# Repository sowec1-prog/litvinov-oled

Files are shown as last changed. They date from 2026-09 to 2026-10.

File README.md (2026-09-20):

# Litvínov OLED scoreboard

Autonomní hokejový panel pro **ESP32-C3 SuperMini** a OLED SSD1306 128×64. Firmware čte kompaktní stav z `https://litvinov-server.onrender.com/api/live`; PC ani LVGL nejsou potřeba.

## Funkce

- živé skóre, týmové kódy a poslední střelec bez diakritiky;
- `TRES-LIT`, `TRES-PCE` nebo `TRES-LIT/PCE` podle strukturované události píšťalky;
- přestávka s lokálním odpočtem bez cloudových dotazů;
- lokální odpočet příštího zápasu;
- gól Litvínova: znělka a 30sekundová blikající animace `GOOL` zprava doleva;
- první přijatý gól po restartu animaci ani zvuk nespustí;
- konečný výsledek se na cloudovém API drží pět minut jako `ZAPAS SKONCIL`.

## Použitý hardware

- **ESP32-C3 SuperMini** — ESP32-C3, 4 MB flash, Wi-Fi 2,4 GHz; projekt používá PlatformIO profil `esp32-c3-devkitm-1`.
- **OLED SSD1306 128 × 64 px**, I²C, adresa `0x3C`.
- **Pasivní piezo bzučák** ověřený pro PWM tóny.
- USB datový kabel pro napájení a nahrání firmwaru.
- Propojovací vodiče: 4× pro OLED, 2× pro bzučák.

## Zapojení

Všechny moduly musí mít společnou zem (**GND**). OLED i GPIO ESP32-C3 jsou 3,3 V logika; OLED proto napájejte z pinu **3V3**, ne z 5 V.

| ESP32-C3 SuperMini | Připojit na | Poznámka |
|---|---|---|
| GPIO8 | OLED SDA | I²C data |
| GPIO9 | OLED SCL | I²C hodiny |
| 3V3 | OLED VCC | napájení OLED |
| GND | OLED GND | společná zem |
| GPIO4 | piezo `+` / signál | PWM znělka |
| GND | piezo `-` | společná zem |

OLED používá I²C adresu `0x3C`.

## Nastavení Wi-Fi

1. Zkopírujte `include/secrets.h.example` jako `include/secrets.h`.
2. Doplňte primární SSID/heslo a případně `WIFI_SSID_2` / `WIFI_PASSWORD_2` a `WIFI_SSID_3` / `WIFI_PASSWORD_3` pro další místa.
3. ESP32-C3 vybere první dostupnou uloženou 2,4GHz síť; po návratu domů se automaticky připojí k domácí Wi-Fi.
4. Pokud se žádná uložená síť nepřipojí do 45 sekund, OLED vytvoří zabezpečený hotspot **`Litvinov-OLED-Setup`** s heslem **`litvinov`**. Připojte se k němu telefonem, otevřete `http://192.168.4.1`, vyberte nalezenou síť a zadejte její heslo. Seznam obsahuje pouze 2,4GHz sítě kompatibilní s ESP32-C3.
5. Po úspěšném připojení hotspot zmizí; nově vybraná síť se uloží do paměti ESP spolu s dříve zadanými sítěmi.
6. Soubor `include/secrets.h` nikdy necommitujte; `.gitignore` jej vylučuje.

## Sestavení a nahrání

Vyžaduje PlatformIO a desku `esp32-c3-devkitm-1`.

```bash
uv run --with platformio pio run
uv run --with esptool esptool --chip esp32c3 --port COM3 --baud 460800 --no-stub write-flash \
  0x0 .pio/build/esp32-c3-devkitm-1/bootloader.bin \
  0x8000 .pio/build/esp32-c3-devkitm-1/partitions.bin \
  0x10000 .pio/build/esp32-c3-devkitm-1/firmware.bin
uv run --with esptool esptool --chip esp32c3 --port COM3 --baud 460800 --no-stub verify-flash \
  0x10000 .pio/build/esp32-c3-devkitm-1/firmware.bin
```

Předchozí funkční flash i zdrojová záloha zůstávají lokálně. Fyzické chování OLED a animace se ověřuje při skutečné nové události v přenosu.

## Použité knihovny

- Adafruit GFX 1.11.11
- Adafruit SSD1306 2.5.13
- ArduinoJson 7.1.0
- espressif32 6.7.0

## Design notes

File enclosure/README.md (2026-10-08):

# Krabička pro Litvínov OLED — revize A

Parametrický OpenSCAD návrh pro přenosný OLED panel. Zdroj: `litvinov_oled_case.scad`.

## Použité rozměry

| Díl | Rozměr použitý v modelu | Zdroj |
|---|---:|---|
| LiPol 855085 s ochranou | 85 × 50 × 8,5 mm | produktový list |
| OLED 1,3" / 7 pin | 35,5 × 33,7 mm; 4 × Ø3,0 mm | dodaný mechanický výkres |
| OLED uchycení | 4 × Ø2,2 mm zatavovací kolík; rozteč 31,5 × 29,7 mm | navrženo podle výkresu |
| ESP32-C3 s piny/bzučákem | 40 × 30 mm obrys | změřeno uživatelem |
| TP4056 USB-C | 20 × 15 × 5 mm | dodaný obrázek modulu |
| SS12F15 | otvor 14 × 3,4 mm | nutno doladit podle konkrétní výšky páčky |

## Konstrukce

- Vnější rozměr: **60 × 96 × 28 mm**.
- Zadní vana drží baterii na dně v prostoru 52 × 87 × 9,5 mm. Baterii nepřiskřípnout: vložit 0,5–1 mm pěnovou pásku, nepoužívat šrouby ani ostré výstupky v jejím okolí.
- Přední díl je bezel pro OLED. Čtyři pružné západky jej drží v zadní vaně; samotný OLED drží čtyři Ø2,2mm plastové kolíky vedené jeho otvory Ø3mm a po zkoušce se zataví páječkou.
- Konstrukce je **bez šroubů**: víčko drží pružné západky a OLED čtyři zatavovací piny. Pro sestavení tedy nejsou potřeba žádné šrouby ani matice.
- Baterie leží při zadní stěně. ESP32-C3 je nalepený svisle na vnitřní stranu předního bezelu pod OLEDem, takže piny zespodu nikdy neleží na LiPol a nahoře zůstává prostor pro bzučák.
- Na **zadní velké ploše** jsou vedle sebe USB-C otvor TP4056 a štěrbina posuvného vypínače. TP4056 se lepí uvnitř přímo za svůj otvor.
- Západky jsou vedené z předního bezelu do nízko umístěných oken zadní vany; bezel se zacvakává z přední strany, ne obráceně.

## Před tiskem: nutné suché ověření

1. Změř šířku a výšku **páčky** konkrétního SS12F15; v modelu jsou parametry `switch_slot_w` a `switch_slot_h`.
2. Zkus nejdřív pouze přední díl a ověř OLED. Rozměr prosvětlené plochy `oled_view_w/h` je startovní hodnota; není to rozměr desky.
3. Pro samostatné STL otevři a exportuj tyto dva soubory: `litvinov_oled_case_FRONT.scad` (přední bezel) a `litvinov_oled_case_REAR.scad` (zadní vana). Hlavní `litvinov_oled_case.scad` nyní ve výchozím nastavení ukazuje oba díly odděleně 8 mm od sebe na jedné tiskové ploše; režim `assembly` je jen kontrolní náhled, nikdy jej neexportuj pro tisk.
4. Tisk pro **FLSun T1 / ABS**: vrstva 0,20 mm, 4 perimetry, 5 horních i spodních vrstev, 18 % gyroid, 8mm brim. Připravený profil `0.20mm ABS enclosure @FLSun T1 - Litvinov` je už uložený přímo v OrcaSliceru. Použij existující filamentový profil **FLSun T1 ABS** (jeho systémové výchozí hodnoty jsou 280 °C tryska / 90 °C podložka). Před tiskem ABS tiskárnu uzavři, vysuš filament a zapni filtraci/odtah podle běžného postupu pro ABS.
5. Přední bezel tiskni čelem dolů, zadní vanu dnem dolů. **Podpěry jsou v profilu vypnuté.** Konstrukce nemá žádné vnitřní police ani kolejnice vyžadující podporu; krátké můstky západek jsou maximálně 1,8 mm.

## Elektrická bezpečnost

- TP4056 připojit k LiPol pouze po ověření polarity `B+` / `B−`.
- USB-C otvor je pro **nabíjení TP4056**, ne pro přímé připojení článku k ESP.
- Baterii nepropichovat, nemačkat, nešroubovat přes ni a nepoužívat ji, pokud je nafouklá nebo se nabíjení zahřívá.
- Než krabičku zavřeš napevno, vyzkoušej nabíjení, vypínač, OLED a bzučák.

## Stav ověření

Model i oba STL soubory byly nyní skutečně vyexportovány přes OpenSCAD a zkontrolovány: každý STL obsahuje právě jeden souvislý tiskový díl. Rozměrová zkouška prvního výtisku zůstává nutná pro konkrétní páčku vypínače, výšku bzučáku a skutečný OLED před zatavením kolíků.

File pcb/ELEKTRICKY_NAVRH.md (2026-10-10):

# Litvínov OLED — elektrický návrh modulové PCB rev. A

Tato deska je nosná PCB pro stávající ESP32-C3 SuperMini. OLED, bzučák, článek 18650 a USB-C nabíjení jsou připojené přes desku; firmware a Wi-Fi anténa SuperMini zůstávají beze změny.

> Stav: návrh zapojení před rozmístěním součástek. Neobjednávat PCB ani nepřipojovat baterii, dokud nebude ověřen skutečný pinový rastr SuperMini, nabíjecí modul a rozměr držáku 18650.

## OLED — univerzální čtyřpinový konektor

OLEDy, které připadají v úvahu, mají oba pořadí `SCL, SDA` na pinech 3/4, ale liší se prohozeným napájením na pinech 1/2:

| Pin OLED konektoru | Typ A | Typ B | Funkce na PCB |
|---:|---|---|---|
| 1 | GND | VIN | volitelné přes pájecí propojku |
| 2 | VIN | GND | volitelné přes pájecí propojku |
| 3 | SCL | SCL | GPIO9 |
| 4 | SDA | SDA | GPIO8 |

- `VIN` OLEDu je vždy **3,3 V**, nikdy 5 V.
- Piny 1 a 2 povedou přes dvě třípadové pájecí propojky, aby se bezpečně zvolilo pořadí napájení podle popisu konkrétního OLEDu.
- Piny SCL a SDA budou mít na PCB vyvedené testpady.

## Bzučák

| Signál | Připojení |
|---|---|
| BUZZER_PWM | GPIO4 ESP32-C3 |
| BUZZER_GND | GND |

Používá se ověřený pasivní piezo bzučák. Pokud se vybere bzučák s vyšším odběrem než bezpečný proud GPIO, doplní se tranzistorový budič; přímé připojení není automaticky předpokládáno.

## 18650, USB-C nabíjení a napájení ESP

- Článek 18650 se nepřipojuje přímo na ESP32 ani na OLED.
- USB-C 5 V vstup vede na nabíječ s ochranou 1S článku (TP4056 s ochranou DW01A/FS8205 nebo elektricky rovnocenné řešení).
- Výstup pro zátěž (`P+`, `P−` u chráněného nabíječe) vede přes vypínač na **stabilizovaný 3,3V buck-boost měnič** pro ESP32 a OLED.
- TP4056 je pouze nabíječ; není to 3,3V regulátor.
- Před finálním PCB je nutné vybrat konkrétní měnič podle špičkového odběru Wi-Fi ESP32-C3 a jeho rozměrů.

## Měření napětí článku

Použít bezpečný dělič přímo z `B+` článku před měničem:

```text
B+ 18650 ── R1 100 kΩ ──┬── ADC_BAT (kandidát GPIO3 ESP32-C3)
                         |
                       R2 100 kΩ
                         |
B− / GND ───────────────┴── GND

ADC_BAT ── C1 100 nF ── GND
```

- Při plně nabitém článku 4,20 V je na ADC maximálně **2,10 V**.
- `V_baterie = V_ADC × 2`.
- `GPIO3` je zatím jen kandidát: firmware ho nyní nepoužívá, ale před layoutem se musí na fyzickém ESP32-C3 SuperMini potvrdit, že je vyvedený a nepoužitý pro bootování.
- Nikdy nepřipojovat `B+` článku přímo na GPIO/ADC.
- Na PCB bude testpad `ADC_BAT` pro porovnání s multimetrem.

## Firmware — dosud nezměněn

Současný firmware používá pouze:

| Funkce | GPIO |
|---|---:|
| OLED SDA | GPIO8 |
| OLED SCL | GPIO9 |
| pasivní bzučák | GPIO4 |

Po fyzickém potvrzení GPIO3 se do firmware doplní průměrování více ADC vzorků, přepočet děličem ×2 a zobrazení napětí. SOC v procentech bude až orientační hodnota, kalibrovaná proti reálnému napětí článku pod běžnou zátěží. Bez zapojeného děliče se firmware nesmí flashovat.

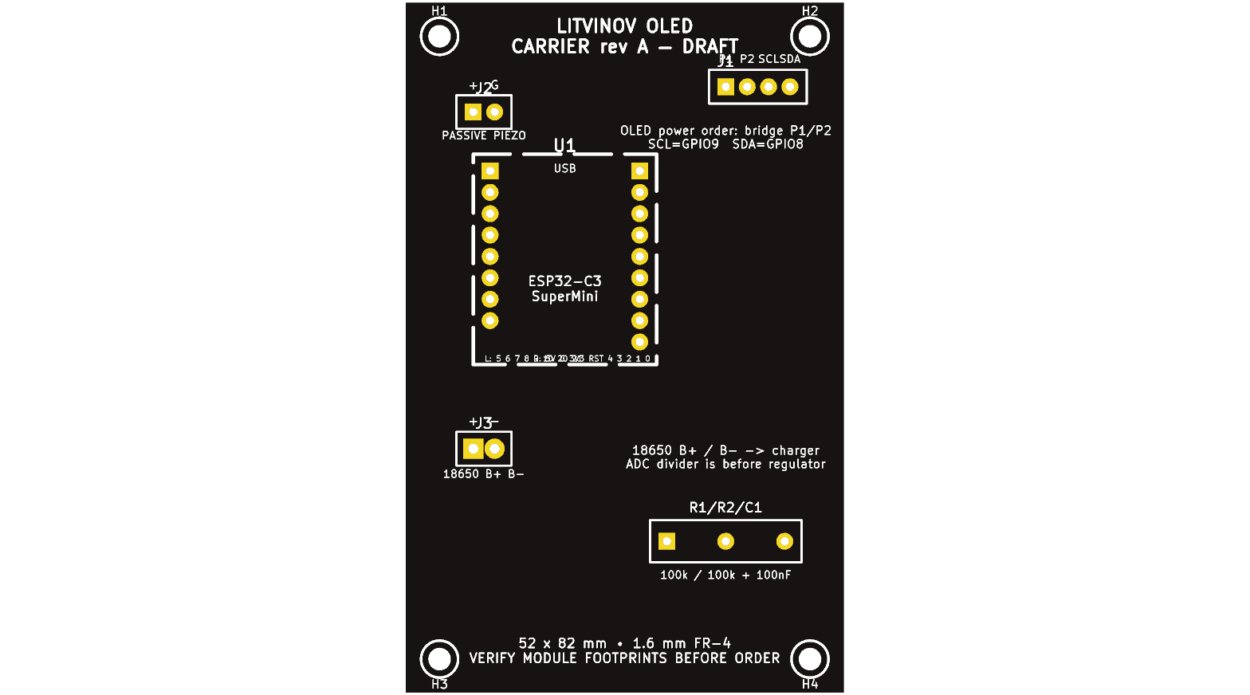
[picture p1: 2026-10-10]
pcb/kicad/litvinov_oled_carrier.png

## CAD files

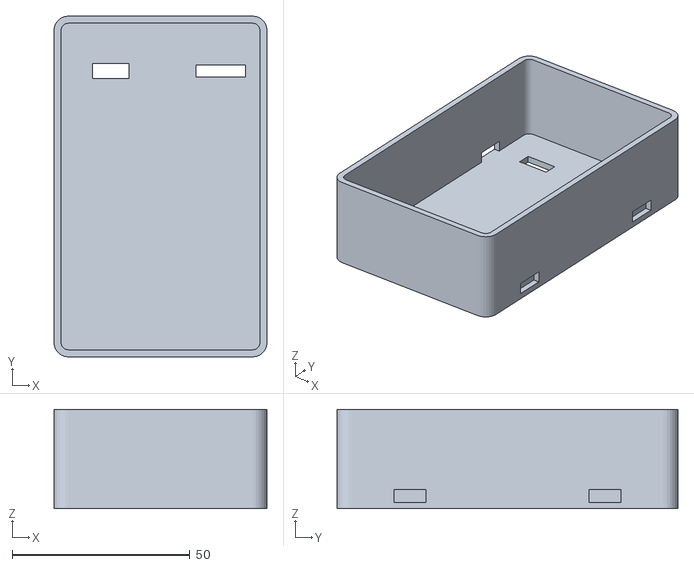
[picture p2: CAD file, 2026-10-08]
enclosure/stl/litvinov_oled_case_REAR.stl
60.0 x 96.0 x 28.0

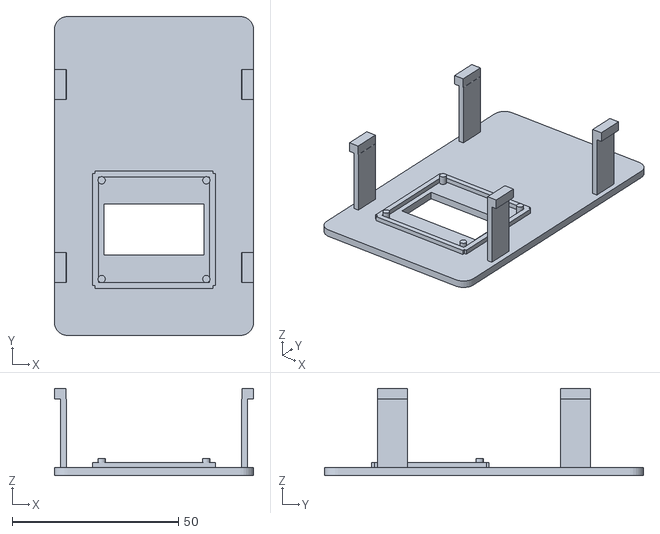
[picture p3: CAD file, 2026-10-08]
enclosure/stl/litvinov_oled_case_FRONT.stl
60.0 x 96.0 x 26.2

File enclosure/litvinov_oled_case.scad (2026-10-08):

/*
  HC Verva Litvínov OLED — snap-fit enclosure, revision A
  Units: mm.  Designed around measured/declared components:
    LiPo 855085: 85 x 50 x 8.5
    ESP32-C3 + headers/buzzer: 40 x 30 (outline; held by rails)
    SH1106 OLED module: 35.4 x 33.5
    USB-C TP4056: 20 x 15 x 5 (per supplied product image)
    SS12F15 slide switch: adjust switch_cut_* after measuring the purchased variant.

  Two printed parts only: FRONT_BEZEL and REAR_TRAY.
  No screws: four printed flex clips latch the bezel into the tray.
*/

$fn = 28;
// Default is a two-piece print plate; wrappers select a part without overwriting it.
current_part = is_undef(part) ? "print_plate" : part;  // front, rear, print_plate, or assembly
fit = 0.35;           // ABS snap clearance; tune 0.30–0.45 for the actual filament/printer
wall = 2.0;

// Overall outside dimensions. Battery dictates the 60 mm width / 96 mm height footprint.
case_w = 60;
case_h = 96;
case_d = 38;          // allows 8.5 mm LiPo + C3 headers/buzzer above it
front_t = 2.4;
corner_r = 4;

// Battery cavity: protected cell is 85 x 50 x 8.5 mm.
batt_w = 52.0;
batt_h = 87.0;
batt_t = 9.5;         // 1 mm vertical clearance; add thin foam, never compress LiPo
batt_x = (case_w - batt_w)/2;
batt_y = 4.5;

// 1.3" 7-pin OLED from the supplied mechanical drawing.
// PCB 35.50 x 33.70 mm; 4 mounting holes Ø3.00 mm, 31.50 x 29.70 mm pitch.
oled_pcb_w = 35.5;
oled_pcb_h = 33.7;
oled_view_w = 31.0;     // 29.42 mm active width + 0.58 mm assembly clearance
oled_view_h = 17.3;     // 14.70 mm active height + 0.60 mm assembly clearance
oled_y = 15;
oled_x = (case_w-oled_pcb_w)/2;
oled_hole_dia = 3.0;
oled_hole_x = 2.5;      // from each PCB side; 35.5 - 2*2 = 31.5 mm pitch
oled_hole_y = 2.5;      // from each PCB side; 33.7 - 2*2 = 29.7 mm pitch
oled_pin_dia = 2.6;     // leaves 0.4 mm radial clearance in an Ø3.0 hole
// 2.8 mm extends 1.6 mm past a nominal 1.2 mm PCB for heat staking.
oled_pin_h = 4.8;

// 2 sajtny pro ESP
translate([85, 58, front_t])
    cube([3, 29, 18]);

translate([105, 58, front_t])
    cube([3, 29, 18]);
    
// ESP32-C3 board outline supplied by user. Retained by rails, not guessed hole locations.
c3_w = 30;
c3_h = 40;
c3_x = (case_w-c3_w)/2;
c3_y = 51;
c3_board_z = batt_t + 1.2;
rail_h = 2.2;
rail_t = 1.5;

// Rear access: TP4056 Type-C module is 20 x 15 x 5 mm from supplied product image.
charge_w = 20;
charge_h = 15;
charge_x = 6;
charge_y = case_h - charge_h ;
usb_slot_w = 10.2;
usb_slot_h = 4.2;

// SS12F15 slider. The listing has several lever heights; use H4 starting point.
switch_slot_w = 8.0;
switch_slot_h = 3.4;
switch_x = case_w - 8 - switch_slot_w;
switch_y = charge_y + 5.8;

// 2 fixační piny pro vypínač – uprav si pozici podle skutečného kusu
switch_pin_d = 1.8;
switch_pin_h = 3.0;

// vlevo od vypínače
translate([switch_x - 3.5, switch_y + switch_slot_h/2, wall])
    cylinder(d=switch_pin_d, h=switch_pin_h);

// vpravo od vypínače
translate([switch_x + switch_slot_w + 3.5, switch_y + switch_slot_h/2, wall])
    cylinder(d=switch_pin_d, h=switch_pin_h);
   
   translate([14.5, 45, wall])
    cylinder(h=3, d=2.4);

    
// Snap joints: one on each side near top/bottom. The bezel is inserted from the front;
// its hooks engage low in the rear tray, on the opposite (rear) side of the joint.
clip_w = 9;
clip_h = 3.2;
clip_z = case_d - 2.5;
clip_window_z = case_d - clip_z+2.5 - clip_h;

module rounded_box(w,h,d,r=3) {
  hull() for (x=[r,w-r]) for (y=[r,h-r])
    translate([x,y,0]) cylinder(h=d,r=r);
}

module rear_tray() {
  difference() {
    rounded_box(case_w,case_h,case_d,corner_r);
    // Main interior, leaves rear floor and side walls.
    translate([wall,wall,wall]) rounded_box(case_w-2*wall,case_h-2*wall,case_d-wall+0.1,corner_r-wall);
    // Rear-face openings: USB-C charge socket and slide switch, both accessible from back.
    // The TP4056 lies flat on the inner rear wall, held by thin VHB tape.
    translate([charge_x + (charge_w-usb_slot_w)/2, charge_y + (charge_h-usb_slot_h)/2, -0.1])
      cube([usb_slot_w,usb_slot_h,wall+0.3]);
    translate([switch_x, switch_y, -0.1])
      cube([switch_slot_w,switch_slot_h,wall+0.3]);
    // Four rear-tray latching windows; hooks come from the front bezel and catch here.
    for (y=[16,case_h-16-clip_w])
      for (x=[-0.1,case_w-wall+0.1])
        translate([x,y,clip_window_z]) cube([wall+0.2,clip_w,clip_h+fit]);
  }

  // Battery is held by its close-fitting pocket plus a thin foam tape pad on the floor.
  // There are deliberately no raised battery lips: this keeps the tray support-free and
  // avoids any sharp printed feature against the LiPo pouch.

  // TP4056 is fixed vertically to the rear wall with thin VHB/foam tape, aligned with
  // the USB-C opening. A printed horizontal shelf would need a support underneath.

  // ESP32-C3 is fixed vertically to the *inside of the front bezel* below the OLED
  // using a thin insulating VHB/foam tape pad. Never tape it onto the LiPo: its
  // underside pins must remain clear of the battery pouch. No guessed mounting holes
  // or suspended rails are used, so the complete rear tray remains support-free.
}

module front_bezel() {
  difference() {
    rounded_box(case_w,case_h,front_t,corner_r);
    // OLED viewing window, centred over the module.
    translate([(case_w-oled_view_w)/2, oled_y+(oled_pcb_h-oled_view_h)/2, -0.1])
      cube([oled_view_w,oled_view_h,front_t+0.2]);
  }

// Four compliant hooks engage rear tray windows.
// aretační lišty jsou součástí víčka
translate([wall + fit+12, wall + fit, front_t])
    cube([case_w - 12*(wall + fit), 1.5, 3]);

translate([wall + fit+12, case_h - wall - fit - 1.5, front_t])
    cube([case_w - 12*(wall + fit), 1.5, 3]);
  
  // Four Ø2.2 heat-stake pins pass through the OLED's 4 × Ø3.0 mounting holes.
  // They start at the bezel's inner face; melt only the top 0.8–1.0 mm after dry-fitting.
  for (px=[oled_hole_x, oled_pcb_w-oled_hole_x])
    for (py=[oled_hole_y, oled_pcb_h-oled_hole_y])
      translate([oled_x+px, oled_y+py+1, front_t])
        cylinder(h=oled_pin_h, d=oled_pin_dia);

  // Edge guides centre the PCB during assembly; the heat-stake pins provide retention.
  for (x=[oled_x-1.2, oled_x+oled_pcb_w-0.8])
    translate([x,oled_y,front_t]) cube([1.8,oled_pcb_h,1.5]);
  //translate([oled_x,oled_y-0.8,front_t]) cube([oled_pcb_w,1.8,1.5]);
  translate([oled_x+5,oled_y+oled_pcb_h-1.0,front_t]) cube([oled_pcb_w-10,1.8,1.5]);

  // Four compliant hooks engage rear tray windows. Print front face down.
  for (y=[16,case_h-16-clip_w]) {
    translate([wall-0.2,y,front_t]) cube([1.8,clip_w,clip_z-front_t]);
    translate([case_w-wall-1.6,y,front_t]) cube([1.8,clip_w,clip_z-front_t]);
    translate([0,y,clip_z]) cube([wall+1.5,clip_w,clip_h]);
    translate([case_w-wall-1.5,y,clip_z]) cube([wall+1.5,clip_w,clip_h]);
  }
}

if (current_part == "rear") rear_tray();
else if (current_part == "front") front_bezel();
else if (current_part == "print_plate") {
  // Two physically separate parts, 8 mm apart, both in their support-free print orientation.
  rear_tray();
  translate([case_w+8,0,0]) front_bezel();
}
else if (current_part == "assembly") {
  // Visual assembly only — never use this mode to export a printable STL.
  rear_tray();
  translate([0,case_h,case_d]) rotate([180,0,0]) front_bezel();
}
else assert(false, str("Unknown part: ", current_part, "; use front, rear, print_plate, or assembly"));

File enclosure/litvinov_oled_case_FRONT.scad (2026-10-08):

// Export this file as STL: front OLED bezel only, support-free orientation.
part = "front";
include <litvinov_oled_case.scad>;

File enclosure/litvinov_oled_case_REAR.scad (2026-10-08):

// Export this file as STL: rear battery/USB-C/switch tray only, support-free orientation.
part = "rear";
include <litvinov_oled_case.scad>;

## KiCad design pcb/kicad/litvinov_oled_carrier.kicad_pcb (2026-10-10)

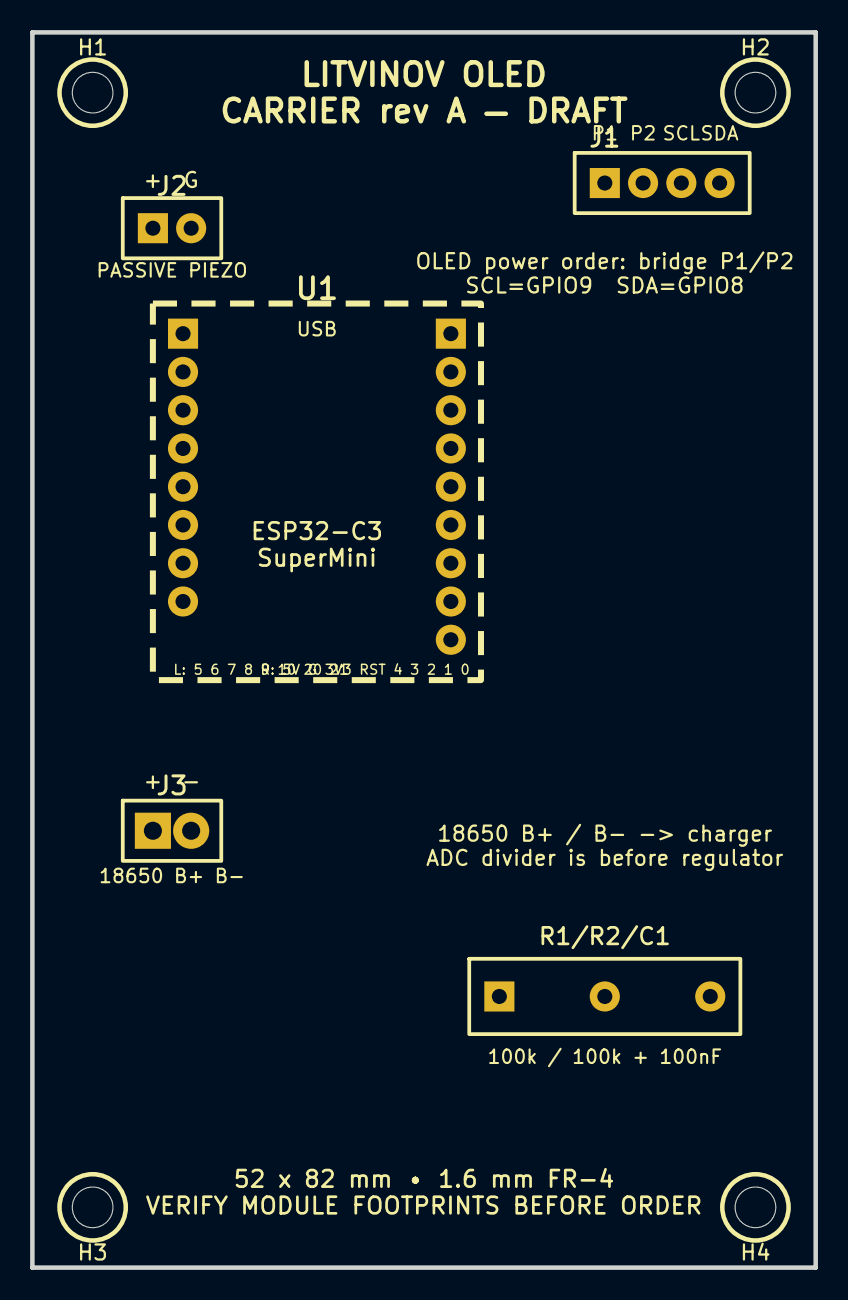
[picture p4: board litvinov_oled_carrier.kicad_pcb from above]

Board: 2 copper layers, 52.0 x 82.0 mm, 9 parts (0 on the bottom side), 6 nets, no tracks yet.

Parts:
H1, H2, H3, H4: M2.5; MountingHole_2.5mm
J1: OLED 1x04: P1 P2 SCL SDA; OLED_1x04_2.54
J2: PASSIVE PIEZO; Buzzer_1x02_2.54
J3: 18650 B+ B-; Battery_1x02_2.54
R1/R2/C1: 100k / 100k + 100nF; ADC_Divider_100k_100k
U1: ESP32-C3 SuperMini; USB end is at top; ESP32-C3-SuperMini_1x08_1x09

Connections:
ADC_BAT_GPIO3: R1/R2/C1.ADC, U1.GPIO3
BATT_RAW: J3.1, R1/R2/C1.BATT
BUZZER_PWM_GPIO4: J2.1, U1.GPIO4
GND: J2.2, J3.2, R1/R2/C1.GND, U1.GND
I2C_SCL_GPIO9: J1.3, U1.GPIO9
I2C_SDA_GPIO8: J1.4, U1.GPIO8

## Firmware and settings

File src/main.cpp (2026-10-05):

#include <Arduino.h>
#include <Wire.h>
#include <WiFi.h>
#include <WebServer.h>
#include <DNSServer.h>
#include <Preferences.h>
#include <HTTPClient.h>
#include <WiFiClientSecure.h>
#include <ArduinoJson.h>
#include <time.h>
#include <Adafruit_GFX.h>
#include <Adafruit_SH110X.h>
#include "esp_wifi.h"
#include "esp_log.h"
#include "hcverva_logo.h"
#include "team_logos.h"
#include "secrets.h"

// Druha sit je volitelna. Stary lokalni secrets.h bez techto maker zustava
// kompatibilni; po doplneni se ESP pripoji k prvni dostupne ulozene siti.
#ifndef WIFI_SSID_2
#define WIFI_SSID_2 ""
#endif
#ifndef WIFI_PASSWORD_2
#define WIFI_PASSWORD_2 ""
#endif
#ifndef WIFI_SSID_3
#define WIFI_SSID_3 ""
#endif
#ifndef WIFI_PASSWORD_3
#define WIFI_PASSWORD_3 ""
#endif

// ESP32-C3 SuperMini + 1,3" OLED SH1106: SDA=GPIO8, SCL=GPIO9.
static constexpr uint8_t OLED_SDA = 8;
static constexpr uint8_t OLED_SCL = 9;
// Bzučák ověřený jako tónový/PWM: signál GPIO4, druhý vodič GND.
static constexpr uint8_t BUZZER_PIN = 4;
static constexpr uint8_t BUZZER_CHANNEL = 0;
static constexpr uint16_t BUZZER_QUARTER_MS = 250;
static constexpr uint8_t BUZZER_GAP_PERCENT = 8;
// Priame spojeni ESP -> Render (bez zavisleho PC).
static constexpr char API_URL[] = "https://litvinov-server.onrender.com/api/live";
// Slabý 2,4GHz signál potřebuje delší okno pro autentizaci a zotavení.
static constexpr uint32_t WIFI_RETRY_MS = 30000;
static constexpr uint32_t POLL_MS = 30000;
// Pri live zapase kontrolujeme data casteji, ale OLED se prekresli jen pri zmene.
static constexpr uint32_t LIVE_POLL_MS = 5000;
// Když se uložené sítě nepřipojí, vznikne lokální konfigurační AP.
// ESP32-C3 při skenu vrací pouze 2,4GHz sítě, takže zde nelze omylem vybrat 5 GHz.
// Portál je až poslední možnost; při slabém signálu se nejdřív několik minut zotavujeme.
static constexpr uint32_t SETUP_PORTAL_DELAY_MS = 180000;
static constexpr char SETUP_AP_SSID[] = "Litvinov-OLED-Setup";
static constexpr char SETUP_AP_PASSWORD[] = "litvinov";
// Preferujeme hlavní síť; záložní sítě zůstávají pravidelně v rotačním pokusu.
static constexpr uint8_t WIFI_ATTEMPT_ORDER[] = {0, 0, 0, 1, 2, 3};
static constexpr byte DNS_PORT = 53;

Adafruit_SH1106G oled(128, 64, &Wire, -1);
WebServer setupServer(80);
DNSServer setupDns;
Preferences preferences;
bool wifiNetworksConfigured = false;
String setupSavedSsid;
String setupSavedPassword;
uint8_t wifiAttemptIndex = 0;
bool setupPortalActive = false;
uint32_t wifiConnectStarted = 0;
uint32_t lastWifiAttempt = 0;
uint32_t lastPoll = 0;
bool liveMode = false;
bool wifiWasConnected = false;
bool countdownActive = false;
uint32_t matchStartEpoch = 0;
uint32_t serverEpoch = 0;
uint32_t serverEpochMillis = 0;
uint8_t tablePosition = 0;  // 1–14, získáno z tabulky extraligy.
String scheduledHome;
String scheduledAway;
String scheduledHomeCode;
String scheduledAwayCode;
String scheduledGameClock;
// Mimo live zápas se střídá nejbližší termín a dvojice klubových znaků po 5 minutách.
static constexpr uint32_t SCHEDULED_PAGE_MS = 5UL * 60UL * 1000UL;
bool scheduledRotationActive = false;
bool scheduledShowingLogo = false;
uint32_t scheduledRotationStarted = 0;
uint32_t shownCountdownSecond = UINT32_MAX;

// ESP si pamatuje jen poslední cloudový event, aby znělku nezopakoval při dalším pollu.
bool audioEventBaselineKnown = false;
String previousAudioEventId;
// Poslední obsah, který už OLED opravdu ukazuje. Stejný cloudový payload nepřekreslujeme.
String lastRenderedPayloadKey;
String lastScheduledIdentity;
bool intermissionActive = false;
uint32_t intermissionUntilEpoch = 0;
uint32_t intermissionServerEpoch = 0;
uint32_t intermissionServerMillis = 0;

// Definice je níže; animace ji používá, aby lišta zůstala vidět i při gólu.
void presentOled();

struct BuzzerNote {
  uint16_t hz;
  uint8_t sixteenths;  // 4=čtvrtka, 16=celá
};

constexpr uint16_t BUZZER_REST = 0;
// Začátek zápasu / gól Litvínova — uložená vítězná znělka.
const BuzzerNote LIT_GOAL_TUNE[] = {
  {370, 16}, {494, 4}, {415, 4}, {494, 4}, {554, 16},
  {BUZZER_REST, 16}, {415, 16}, {554, 4}, {466, 4}, {554, 4}, {494, 16},
};
// Inkasovaný gól — samostatný pomalý sestupný motiv, zřetelně jiný než oslavná znělka.
const BuzzerNote CONCEDED_GOAL_TUNE[] = {
  {523, 4}, {466, 4}, {415, 4}, {370, 8},
  {BUZZER_REST, 4}, {370, 4}, {311, 4}, {277, 12},
};

void playBuzzerTune(const BuzzerNote* tune, size_t count) {
  for (size_t i = 0; i < count; ++i) {
    const uint16_t duration = (BUZZER_QUARTER_MS * tune[i].sixteenths) / 4;
    if (tune[i].hz == BUZZER_REST) {
      ledcWriteTone(BUZZER_CHANNEL, 0);
      delay(duration);
      continue;
    }
    const uint16_t soundDuration = duration - (duration * BUZZER_GAP_PERCENT / 100);
    ledcWriteTone(BUZZER_CHANNEL, tune[i].hz);
    delay(soundDuration);
    ledcWriteTone(BUZZER_CHANNEL, 0);
    delay(duration - soundDuration);
  }
}

// Samostatná FreeRTOS úloha zachová původní délky not, zatímco hlavní úloha kreslí GOOL.
void playLitGoalTuneTask(void*) {
  playBuzzerTune(LIT_GOAL_TUNE, sizeof(LIT_GOAL_TUNE) / sizeof(LIT_GOAL_TUNE[0]));
  vTaskDelete(nullptr);
}

// Litvínovský gól: GOOL jede zprava doleva v prvním řádku pod trvalou lištou.
// Při každém průjezdu přibývají písmena postupně: G → GO → GOO → GOOL.
// Zvuk i GOOL se spustí zároveň, ale běží nezávisle: znělka skončí po své
// původní délce a 30sekundová animace doběhne samostatně.
void playLitGoalAnimation() {
  static constexpr uint32_t GOAL_ANIMATION_MS = 30000;
  static constexpr uint16_t FRAME_MS = 70;
  static constexpr uint16_t PASS_MS = 2800;
  static constexpr uint16_t LETTER_STEP_MS = 350;
  // Horní lišta má 8 px; první řádek obsahu začíná hned pod ní.
  static constexpr int16_t GOAL_TEXT_Y = 9;
  const String fullMessage = "GOOL";
  const uint8_t textSize = 4;
  int16_t x1, y1;
  uint16_t fullTextWidth, textHeight;
  oled.setTextSize(textSize);
  oled.getTextBounds(fullMessage, 0, 0, &x1, &y1, &fullTextWidth, &textHeight);
  const uint32_t started = millis();
  oled.setTextWrap(false);  // Text mimo pravý okraj nesmí přeskočit do druhého řádku.

  while (millis() - started < GOAL_ANIMATION_MS) {
    const uint32_t elapsed = millis() - started;
    const uint32_t passElapsed = elapsed % PASS_MS;
    const uint8_t letterCount = min<uint8_t>(fullMessage.length(), 1 + passElapsed / LETTER_STEP_MS);
    const String message = fullMessage.substring(0, letterCount);
    const int16_t x = 128 - ((128 + fullTextWidth) * passElapsed / PASS_MS);

    oled.clearDisplay();
    oled.setTextColor(SH110X_WHITE);
    oled.setTextSize(textSize);
    oled.setCursor(x, GOAL_TEXT_Y);
    oled.print(message);
    presentOled();
    delay(FRAME_MS);
  }
  oled.setTextWrap(true);
}

bool handleAudioCue(const String& eventId, const String& cue) {
  // První odpověď po startu pouze nastaví baseline, aby se nepřehrál starší gól.
  if (!audioEventBaselineKnown) {
    previousAudioEventId = eventId;
    audioEventBaselineKnown = true;
    return false;
  }
  if (eventId.isEmpty() || eventId == previousAudioEventId) return false;

  previousAudioEventId = eventId;
  if (cue == "lit_goal") {
    Serial.println("CLOUD_AUDIO=lit_goal");
    const BaseType_t audioTaskStarted = xTaskCreate(playLitGoalTuneTask, "litGoalTone", 2048, nullptr, 1, nullptr);
    if (audioTaskStarted != pdPASS) {
      Serial.println("AUDIO_TASK_FAILED");
      playBuzzerTune(LIT_GOAL_TUNE, sizeof(LIT_GOAL_TUNE) / sizeof(LIT_GOAL_TUNE[0]));
    }
    playLitGoalAnimation();
    return true;  // Obnovime aktualni live obrazovku hned po animaci.
  } else if (cue == "conceded_goal") {
    Serial.println("CLOUD_AUDIO=conceded_goal");
    playBuzzerTune(CONCEDED_GOAL_TUNE, sizeof(CONCEDED_GOAL_TUNE) / sizeof(CONCEDED_GOAL_TUNE[0]));
  }
  return false;
}

// Stav Wi-Fi je trvalá horní lišta. Všechny obrazovky začínají až pod ní.
static constexpr int16_t WIFI_BAR_HEIGHT = 8;
// Čárky se obnoví jednou za 10 s; nepouští Wi-Fi scan, jen čte aktuální RSSI.
static constexpr uint32_t WIFI_BAR_REFRESH_MS = 10000;
uint32_t lastWifiBarRefresh = 0;

String formatHeaderTime() {
  if (serverEpoch == 0 || serverEpochMillis == 0) return "--:--";
  const time_t now = serverEpoch + (millis() - serverEpochMillis) / 1000;
  struct tm localTime {};
  localtime_r(&now, &localTime);
  char text[6];
  snprintf(text, sizeof(text), "%02d:%02d", localTime.tm_hour, localTime.tm_min);
  return String(text);
}

void drawWifiStatusBar() {
  // Trvalá hlavička: pořadí v tabulce vlevo, skutečný čas uprostřed, Wi-Fi vpravo.
  oled.fillRect(0, 0, 128, WIFI_BAR_HEIGHT, SH110X_BLACK);
  oled.setTextColor(SH110X_WHITE);
  oled.setTextSize(1);
  oled.setCursor(0, 0);
  if (tablePosition > 0) {
    oled.print(String(tablePosition) + ".");
  } else {
    oled.print("--");
  }
  oled.setCursor(49, 0);
  oled.print(formatHeaderTime());

  if (WiFi.status() != WL_CONNECTED) {
    // X = odpojeno; tři tečky = aktivní lokální setup portál.
    if (setupPortalActive) {
      oled.fillCircle(113, 4, 1, SH110X_WHITE);
      oled.fillCircle(118, 4, 1, SH110X_WHITE);
      oled.fillCircle(123, 4, 1, SH110X_WHITE);
    } else {
      oled.drawLine(116, 1, 124, 7, SH110X_WHITE);
      oled.drawLine(124, 1, 116, 7, SH110X_WHITE);
    }
    return;
  }

  const int rssi = WiFi.RSSI();
  uint8_t bars = 0;
  if (rssi >= -60) bars = 4;
  else if (rssi >= -67) bars = 3;
  else if (rssi >= -75) bars = 2;
  else if (rssi >= -82) bars = 1;

  for (uint8_t i = 0; i < 4; ++i) {
    const int16_t x = 110 + i * 4;
    const int16_t height = 2 + i * 2;
    if (i < bars) oled.fillRect(x, 7 - height, 3, height, SH110X_WHITE);
    else oled.drawRect(x, 7 - height, 3, height, SH110X_WHITE);
  }
}

void presentOled() {
  drawWifiStatusBar();
  oled.display();
}

void printCentered(const String &text, int16_t y, uint8_t size) {
  int16_t x1, y1;
  uint16_t width, height;
  oled.setTextSize(size);
  oled.getTextBounds(text, 0, y, &x1, &y1, &width, &height);
  oled.setCursor(width >= 128 ? 0 : (128 - width) / 2, y);
  oled.print(text);
}

void screen(const String &a, const String &b = "", const String &c = "", const String &d = "") {
  oled.clearDisplay();
  oled.setTextColor(SH110X_WHITE);
  oled.setTextSize(1);
  oled.setCursor(0, 9);
  oled.println(a);
  oled.println(b);
  oled.println(c);
  oled.println(d);
  presentOled();
}

const uint8_t* teamLogoForCode(String code) {
  code.toUpperCase();
  if (code == "TRI") return LOGO_TRI;
  if (code == "LIT") return LOGO_LIT;
  if (code == "KLA") return LOGO_KLA;
  if (code == "OLO") return LOGO_OLO;
  if (code == "LIB") return LOGO_LIB;
  if (code == "MHK") return LOGO_MHK;
  if (code == "PLZ") return LOGO_PLZ;
  if (code == "KOM") return LOGO_KOM;
  if (code == "PCE") return LOGO_PCE;
  if (code == "VIT") return LOGO_VIT;
  return nullptr;
}

void screenVervaLogo() {
  // Startovní / síťová obrazovka zůstává klubový znak; dvojice znaků je jen ve scheduled cyklu.
  oled.clearDisplay();
  oled.drawBitmap((128 - HC_VERVA_LOGO_WIDTH) / 2, WIFI_BAR_HEIGHT + 1,
                  HC_VERVA_LOGO, HC_VERVA_LOGO_WIDTH, HC_VERVA_LOGO_HEIGHT, SH110X_WHITE);
  presentOled();
}

void screenFixtureLogos(const String& homeCode, const String& awayCode) {
  // Stránka střídající rozpis: pouze dva znaky, DOMA vlevo a HOSTÉ vpravo.
  // Trvalá horní lišta zůstává zachovaná přes presentOled().
  const uint8_t* homeLogo = teamLogoForCode(homeCode);
  const uint8_t* awayLogo = teamLogoForCode(awayCode);
  oled.clearDisplay();
  if (homeLogo) oled.drawBitmap(10, WIFI_BAR_HEIGHT + 8, homeLogo, LOGO_W, LOGO_H, SH110X_WHITE);
  if (awayLogo) oled.drawBitmap(78, WIFI_BAR_HEIGHT + 8, awayLogo, LOGO_W, LOGO_H, SH110X_WHITE);
  presentOled();
}

String normalizeDate(String dateTime) {
  String time = dateTime.length() >= 5 ? dateTime.substring(dateTime.length() - 5) : "--:--";
  String date = dateTime.length() > 6 ? dateTime.substring(0, dateTime.length() - 6) : dateTime;
  date.replace("ÚT", "UT");
  date.replace("ČT", "CT");
  date.replace("PÁ", "PA");
  date.replace(". ", ".");
  if (date.endsWith(".")) date.remove(date.length() - 1);
  return date + " " + time;
}

String formatCountdown(uint32_t remaining) {
  if (remaining >= 3600) return "ZA " + String(remaining / 3600) + " H";
  if (remaining >= 600) return "ZA " + String(remaining / 60) + " MIN";
  char text[12];
  snprintf(text, sizeof(text), "%02lu:%02lu", remaining / 60, remaining % 60);
  return text;
}

void screenLive(const String &homeCode, const String &awayCode, int homeScore, int awayScore, const String &clock, const String &penaltyIndicator) {
  const String teams = homeCode + "-" + awayCode;
  const String score = String(homeScore) + ":" + String(awayScore);
  oled.clearDisplay();
  oled.setTextColor(SH110X_WHITE);
  // Horních 8 px trvale zabírá Wi-Fi lišta.
  printCentered(teams, 9, 1);
  printCentered(score, 19, 3);
  if (!penaltyIndicator.isEmpty()) printCentered(penaltyIndicator, 45, 1);
  printCentered(clock, penaltyIndicator.isEmpty() ? 48 : 55, 1);
  presentOled();
}

void screenFinished(const String &homeCode, const String &awayCode, int homeScore, int awayScore) {
  oled.clearDisplay();
  oled.setTextColor(SH110X_WHITE);
  printCentered(homeCode + "-" + awayCode, 9, 1);
  printCentered(String(homeScore) + ":" + String(awayScore), 19, 2);
  printCentered("ZAPAS", 38, 1);
  printCentered("SKONCIL", 51, 1);
  presentOled();
}

void screenFixture(const String &home, const String &away, const String &bottom, uint8_t bottomSize) {
  oled.clearDisplay();
  oled.setTextColor(SH110X_WHITE);
  // Domácí LIT je natrvalo v liště; tabulka tak má více místa pro soupeře a termín.
  if (home.isEmpty()) {
    printCentered("proti", 15, 1);
    printCentered(away, 28, 1);
  } else {
    printCentered(home, 9, 1);
    printCentered("proti", 20, 1);
    printCentered(away, 31, 1);
  }
  printCentered(bottom, 46, bottomSize);
  presentOled();
}

void screenBigScheduled(const String &home, const String &away, const String &dateTime) {
  // Pořadí v liště není název klubu; pro soupeře musí zůstat vidět oba týmy.
  screenFixture(home, away, normalizeDate(dateTime), 1);
}

void screenCountdown(uint32_t remaining) {
  screenFixture(scheduledHome, scheduledAway, formatCountdown(remaining), 2);
}

bool shouldShowScheduledLogo() {
  if (!scheduledRotationActive) return false;
  const uint32_t phase = (millis() - scheduledRotationStarted) / SCHEDULED_PAGE_MS;
  return (phase % 2) == 1;
}

void refreshScheduledRotation(bool force = false) {
  if (!scheduledRotationActive) return;
  const bool showLogo = shouldShowScheduledLogo();
  if (!force && showLogo == scheduledShowingLogo) return;

  scheduledShowingLogo = showLogo;
  shownCountdownSecond = UINT32_MAX;
  if (showLogo) {
    screenFixtureLogos(scheduledHomeCode, scheduledAwayCode);
    Serial.printf("OLED_SCHEDULED_PAGE=logos home=%s away=%s\n", scheduledHomeCode.c_str(), scheduledAwayCode.c_str());
    return;
  }

  if (countdownActive && matchStartEpoch > serverEpoch) {
    const uint32_t now = serverEpoch + (millis() - serverEpochMillis) / 1000;
    screenCountdown(matchStartEpoch - now);
  } else {
    screenBigScheduled(scheduledHome, scheduledAway, scheduledGameClock);
  }
  Serial.println("OLED_SCHEDULED_PAGE=fixture");
}

void refreshCountdown() {
  if (!countdownActive || matchStartEpoch == 0 || serverEpoch == 0 || scheduledShowingLogo) return;
  const uint32_t now = serverEpoch + (millis() - serverEpochMillis) / 1000;
  const uint32_t remaining = matchStartEpoch > now ? matchStartEpoch - now : 0;
  if (remaining != shownCountdownSecond) {
    shownCountdownSecond = remaining;
    screenCountdown(remaining);
  }
}

void onWifiEvent(WiFiEvent_t event, WiFiEventInfo_t info) {
  switch (event) {
    case ARDUINO_EVENT_WIFI_STA_START:
      ESP_LOGI("LIT", "WIFI_EVENT=STA_START");
      Serial.println("WIFI_EVENT=STA_START");
      break;
    case ARDUINO_EVENT_WIFI_STA_CONNECTED:
      ESP_LOGI("LIT", "WIFI_EVENT=STA_CONNECTED");
      Serial.println("WIFI_EVENT=STA_CONNECTED");
      break;
    case ARDUINO_EVENT_WIFI_STA_GOT_IP:
      ESP_LOGI("LIT", "WIFI_EVENT=GOT_IP ip=%s rssi=%d", WiFi.localIP().toString().c_str(), WiFi.RSSI());
      Serial.printf("WIFI_EVENT=GOT_IP ip=%s rssi=%d\n", WiFi.localIP().toString().c_str(), WiFi.RSSI());
      break;
    case ARDUINO_EVENT_WIFI_STA_DISCONNECTED:
      ESP_LOGW("LIT", "WIFI_EVENT=DISCONNECTED reason=%d", info.wifi_sta_disconnected.reason);
      Serial.printf("WIFI_EVENT=DISCONNECTED reason=%d\n", info.wifi_sta_disconnected.reason);
      break;
    default:
      break;
  }
}

void htmlOption(String &page, const String &ssid) {
  String escaped = ssid;
  escaped.replace("&", "&amp;");
  escaped.replace("<", "&lt;");
  escaped.replace(">", "&gt;");
  escaped.replace("\"", "&quot;");
  page += "<option value=\"" + escaped + "\">" + escaped + "</option>";
}

void showSetupPage() {
  const int count = WiFi.scanNetworks(false, true);
  String page = "<!doctype html><meta name=viewport content='width=device-width,initial-scale=1'>"
                "<title>Litvinov OLED Wi-Fi</title><style>body{font-family:sans-serif;max-width:32rem;margin:2rem auto;padding:0 1rem}input,select,button{box-sizing:border-box;width:100%;font-size:1rem;padding:.7rem;margin:.4rem 0}button{background:#bd0000;color:white;border:0;border-radius:.3rem}</style>"
                "<h2>Litvinov OLED - Wi-Fi</h2><p>Jsou zde jen site 2,4 GHz, ktere ESP32-C3 umi pouzit. Pokud sit v seznamu chybi, napis jeji presny nazev rucne.</p>"
                "<form method=post action=/save><label>Wi-Fi sit</label><input name=ssid list=ssids placeholder='Presny nazev Wi-Fi' required><datalist id=ssids>";
  for (int i = 0; i < count; ++i) htmlOption(page, WiFi.SSID(i));
  page += "</datalist>";
  if (count <= 0) page += "<p>Zadna sit pri skenu nenalezena. Rucni zadani funguje normalne.</p>";
  page += "<label>Heslo Wi-Fi</label><input name=pass type=password autocomplete=current-password required>"
          "<button type=submit>Ulozit a pripojit</button></form><p>Po ulozeni se OLED sam pripoji a tento hotspot zmizi.</p>";
  setupServer.send(200, "text/html; charset=utf-8", page);
}

void saveSetupWifi() {
  const String ssid = setupServer.arg("ssid");
  const String password = setupServer.arg("pass");
  if (ssid.isEmpty() || password.isEmpty()) {
    setupServer.send(400, "text/plain; charset=utf-8", "Chybi nazev site nebo heslo.");
    return;
  }
  preferences.begin("wifi", false);
  preferences.putString("setup_ssid", ssid);
  preferences.putString("setup_pass", password);
  preferences.end();
  setupServer.send(200, "text/html; charset=utf-8", "<meta name=viewport content='width=device-width'><h2>Overuji pripojeni OLED...</h2><p>Vyckej asi pul minuty. Po uspechu hotspot zmizi.</p>");
  WiFi.begin(ssid.c_str(), password.c_str());
  screen("OVERUJI WIFI", "VYBRANA 2.4G SIT");
  wifiConnectStarted = millis();
}
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
void loop() {
  static uint32_t lastDiag = 0;
  if (millis() - lastDiag >= 5000) {
    lastDiag = millis();
    ESP_LOGI("LIT", "HEARTBEAT wifi_status=%d ip=%s portal=%d", WiFi.status(), WiFi.localIP().toString().c_str(), setupPortalActive);
    Serial.printf("HEARTBEAT wifi_status=%d ip=%s portal=%d\n", WiFi.status(), WiFi.localIP().toString().c_str(), setupPortalActive);
  }
  // Překreslí pouze osmipixelovou Wi-Fi lištu nad stávajícím obsahem;
  // nezastaví polling, portál ani běžné obrazovky.
  if (millis() - lastWifiBarRefresh >= WIFI_BAR_REFRESH_MS) {
    lastWifiBarRefresh = millis();
    drawWifiStatusBar();
    oled.display();
  }
  if (WiFi.status() != WL_CONNECTED) {
    wifiWasConnected = false;
    if (setupPortalActive) {
      setupDns.processNextRequest();
      setupServer.handleClient();
      // Portál je fallback, nikoli konečný stav: dále zkoušíme uložené Wi-Fi.
      if (millis() - lastWifiAttempt >= WIFI_RETRY_MS) startWifi();
      delay(10);
      return;
    }
    if (wifiConnectStarted != 0 && millis() - wifiConnectStarted >= SETUP_PORTAL_DELAY_MS) {
      startSetupPortal();
      return;
    }
    if (millis() - lastWifiAttempt >= WIFI_RETRY_MS) startWifi();
    delay(100);
    return;
  }

  stopSetupPortal();
  wifiConnectStarted = 0;

  if (!wifiWasConnected) {
    wifiWasConnected = true;
    screen("Wi-Fi PRIPOJENA", WiFi.localIP().toString(), String(WiFi.RSSI()) + " dBm");
    Serial.printf("CONNECTED ip=%s rssi=%d\n", WiFi.localIP().toString().c_str(), WiFi.RSSI());
    delay(2500);
    lastPoll = 0; // Nacti zapas hned po zobrazeni uspesneho pripojeni.
  }

  // Mimo live zápas střídáme po 10 minutách nejbližší termín a logo HC Verva.
  refreshScheduledRotation();
  refreshCountdown();

  // U naplanovaneho zapasu je datum/cas uz pevny. Cloud znovu dotazeme az
  // presne pri startu, kdy se muze zmenit stav na live a prijde online skore.
  if (countdownActive && matchStartEpoch > 0 && serverEpoch > 0) {
    const uint32_t now = serverEpoch + (millis() - serverEpochMillis) / 1000;
    if (now < matchStartEpoch) {
      delay(100);
      return;
    }
    countdownActive = false;
    lastPoll = 0;
  }

  if (intermissionActive && intermissionUntilEpoch > 0 && intermissionServerEpoch > 0) {
    const uint32_t now = intermissionServerEpoch + (millis() - intermissionServerMillis) / 1000;
    if (now < intermissionUntilEpoch) {
      delay(100);
      return;  // Během přestávky se cloud zbytečně nedotazuje.
    }
    intermissionActive = false;
    lastPoll = 0;
  }

  const uint32_t pollInterval = liveMode ? LIVE_POLL_MS : POLL_MS;
  if (millis() - lastPoll >= pollInterval) {
    lastPoll = millis();
    fetchAndDisplayMatch();
  }
  delay(100);
}

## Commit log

2026-09-18 Document hardware and wiring
2026-09-23 Keep both teams visible in fixture view
    [main.cpp]
2026-09-26 Add Litvinov buzzer boot test
    [main.cpp]
2026-09-26 Revert "Add Litvinov buzzer boot test"
    This reverts commit 6e23630cc7f391a5a4b525b5d99e8c044e215613.
    [main.cpp]
2026-10-03 Rotate fixture and Verva logo every ten minutes
    [main.cpp]
2026-10-05 feat: show scheduled fixture logos
    [main.cpp]
2026-10-08 feat: add printable screwless OLED enclosure
    [litvinov_oled_case.scad, litvinov_oled_case_FRONT.scad, litvinov_oled_case_FRONT.stl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]
2026-10-10 draft: add KiCad carrier PCB layout
    [litvinov_oled_carrier.kicad_pcb, litvinov_oled_carrier.kicad_sch]
2026-10-10 fix: map ESP32-C3 SuperMini header pinout
    [litvinov_oled_carrier.kicad_pcb]
2026-10-16 docs: recommend ESP32-C3 antenna improvement
2026-10-22 Align buzzer pin with PCB revision A
